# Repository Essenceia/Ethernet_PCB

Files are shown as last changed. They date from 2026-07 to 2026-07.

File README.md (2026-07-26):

# PCBs for Coffee-Shop project

## Biscotti 

x1 Ethernet Pmod for full-duplex 100BASE-TX over RMII using the LAN8720A chip. 

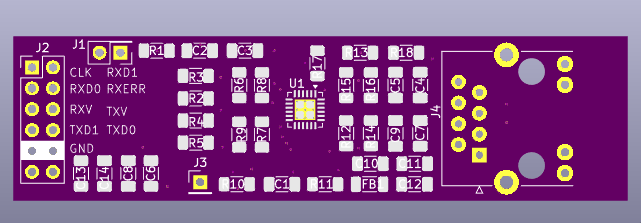
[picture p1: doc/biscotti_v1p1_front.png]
front

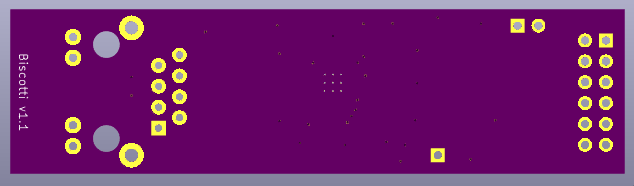
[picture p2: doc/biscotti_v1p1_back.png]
back


## AI Policy 

No AI was used by me in the development of this hardware. 

All code and design decisions are, and will remain, entirely human made. 

## License 

Copyright Julia Desmazes, 2026 

This hardware is distributed under the **strongly** reciprocal CERN Open Hardware Licence Version 2 unless
otherwise specified.

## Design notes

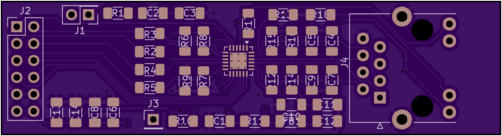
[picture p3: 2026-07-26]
doc/biscotti_v1_0_front.png

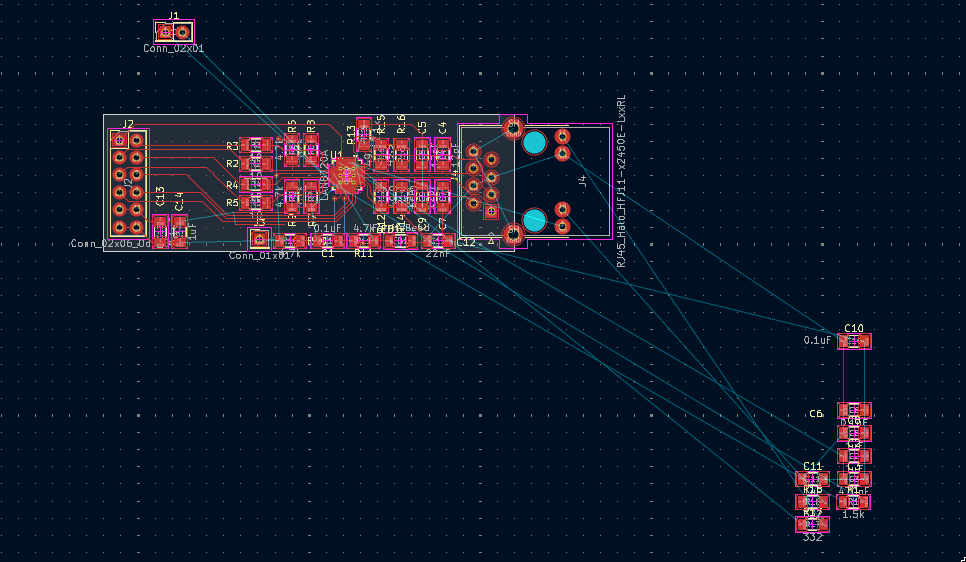
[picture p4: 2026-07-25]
doc/layout_biscotti_wip.png

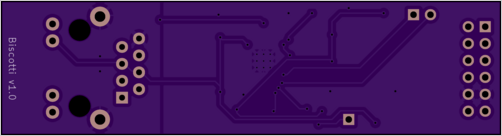
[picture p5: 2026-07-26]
doc/biscotti_v1_0_back.png

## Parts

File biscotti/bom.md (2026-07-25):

All right belong to Julia Desmazes, 2026.

This document is human made and authorization is explicitely 
not granted for this document to be used as part of any trainig 
or inference dataset. 

# LAN8720A 

PHY chip, 24-QFN

package: 24-QFN
 
part: LAN8720A-CP-TR
digikey part number: LAN8720A-CP-CT-ND

https://www.digikey.com/en/products/detail/microchip-technology/LAN8720A-CP-TR/3872109

# RJ45 Jack

ARJM11 Series of RJ45 Jacks, 100BASE-T, yellow-green leds

part: ARJM11D7-009-AB-EW2
digikey part number: 535-ARJM11D7-009-AB-EW2-ND

https://www.digikey.com/en/products/detail/abracon-llc/ARJM11D7-009-AB-EW2/7675229 

# 12pF Ceramic Capacitor

12pF ceramic capacitors for decoupling the data lines between the PHY chip and the RJ45 connector for EMI.
Targetting 1206 (i) flootprint (3216 m). 

package: 1206 

part: GMC31CG120J100NT
digikey part number: 4713-GMC31CG120J100NTCT-ND

https://www.digikey.com/en/products/detail/cal-chip-electronics-inc/GMC31CG120J100NT/25893198

# 49.9 ohm Resistor 

package: 1206 

part: RC1206FR-0749R9L
digikey part number: 311-49.9FRCT-ND

https://www.digikey.com/en/products/detail/yageo/RC1206FR-0749R9L/728942

# 332 ohm Resistor 

package: 1206 

part: RK73H2BTTD3320F
digikey part number: 2019-RK73H2BTTD3320FCT-ND

https://www.digikey.com/en/products/detail/koa-speer-electronics-inc/RK73H2BTTD3320F/10235876

# 22nF Ceramic Capacitor 

package: 1206

part: 1206B223K500CT
digikey part number: 1292-1609-1-ND

https://www.digikey.com/en/products/detail/walsin-technology-corporation/1206B223K500CT/9355106

# 12.1k ohm Resistor 

Used for RBIAS, need 12.1k 1% as per spec. 

package: 1206

part: RMCF1206FT12K1
digikey part number: RMCF1206FT12K1CT-ND

https://www.digikey.com/en/products/detail/stackpole-electronics-inc/RMCF1206FT12K1/1759578

# 1.5k ohm Resistor 

Used for pull-up of MDIO

package: 1206

part: RMCF1206JG1K50
digikey part number: RMCF1206JG1K50CT-ND

https://www.digikey.com/en/products/detail/stackpole-electronics-inc/RMCF1206JG1K50/1757378

# 4.7k ohm Resistor 

Used for pull-up of nRST, don't want to drive that from the logic. 

package: 1206 

part: RC1206FR-074K7L
digikey part number: 311-4.70KFRCT-ND

https://www.digikey.com/en/products/detail/yageo/RC1206FR-074K7L/728887

# 100nF (0.1uF) Ceramic capcitor

Pull nRST to GND during reset

package: 1206

part: C1206C104K5RACTU
digikey part number: 399-C1206C104K5RACTUCT-ND

https://www.digikey.com/en/products/detail/kemet/C1206C104K5RACTU/411248

# 1uF Cermaic capacitor

package: 1206

part: GMC31Y5V105Z50NT
digikey part number: 4713-GMC31Y5V105Z50NTCT-ND

https://www.digikey.com/en/products/detail/cal-chip-electronics-inc/GMC31Y5V105Z50NT/26225549

# 470pF Ceramic Capacitor 

package: 1206 

part: GMC31CG471J100NT
digikey part number: 4713-GMC31CG471J100NTCT-ND

https://www.digikey.com/en/products/detail/cal-chip-electronics-inc/GMC31CG471J100NT/25951946

# 10 ohm Resitor 

RX data lines

package: 1206

part: RMCF1206JT10R0
digikey part: RMCF1206JT10R0CT-ND

https://www.digikey.com/en/products/detail/stackpole-electronics-inc/RMCF1206JT10R0/1757340

# Power line Ferrit Bead

Seperate VDD and AVDD for noise, 390 Ohms @ 100MHz, 2A/50mOhm
package: 1206

part: MI1206L391R-10
digikey key: 240-2578-1-ND

https://www.digikey.com/en/products/detail/laird-signal-integrity-products/MI1206L391R-10/1287224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

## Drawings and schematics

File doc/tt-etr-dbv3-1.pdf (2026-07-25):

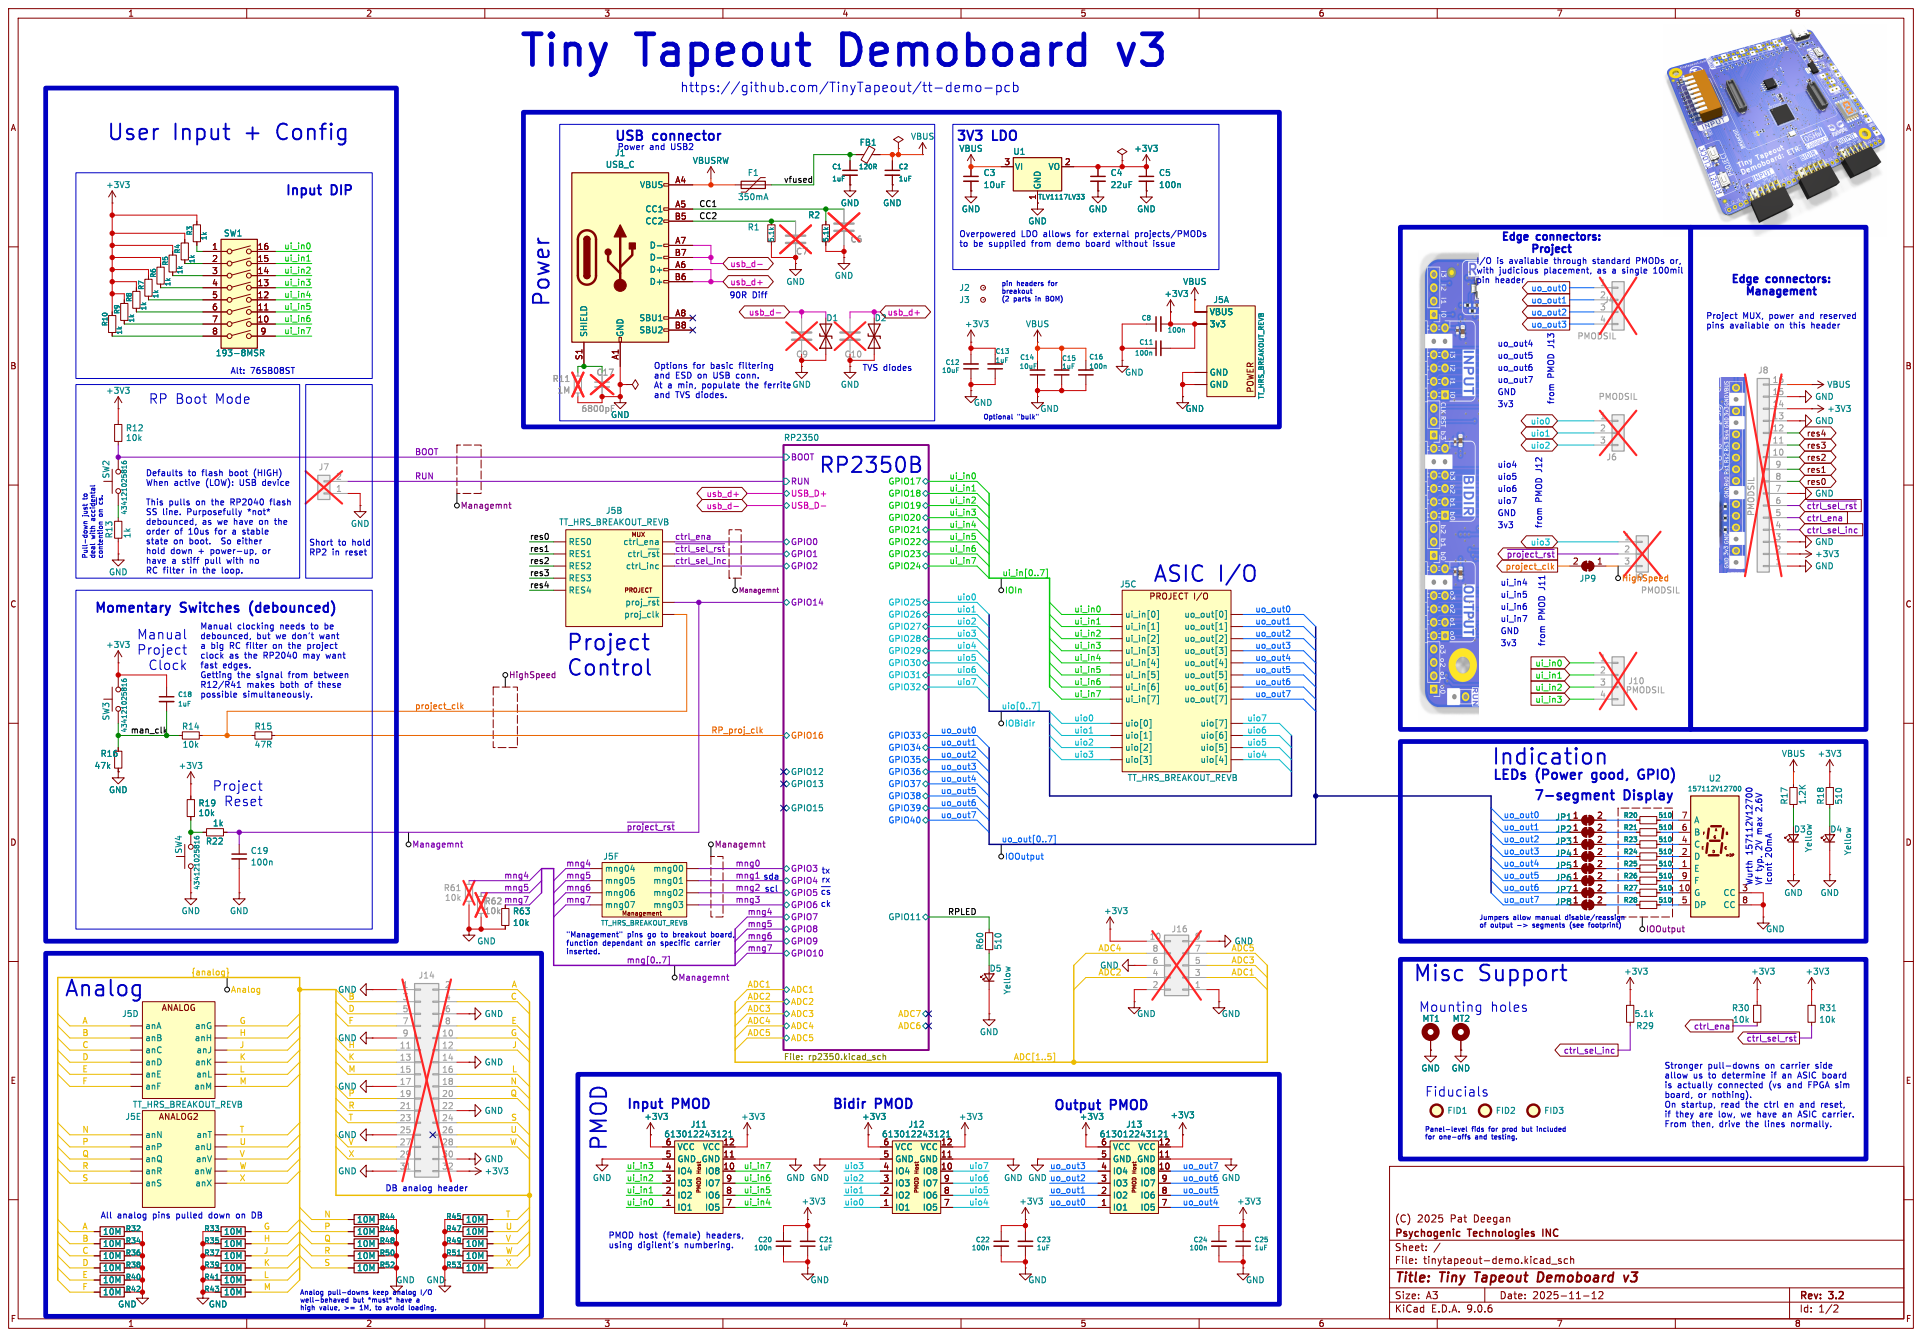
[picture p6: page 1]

Tiny Tapeout Demoboard v3 Pull-down just to deal with accidental contention on ~{cs}.

https://github.com/TinyTapeout/tt-demo-pcb
vfused

and TVS diodes. Input DIP

Edge connectors: Project from PMOD J12uio4
uo_out4

pin headers for breakout (2 parts in BOM)

Project MUX, power and reserved

Options for basic filtering

ck RP Boot Mode

order of 10us for a stable

Short to hold RP2 in reset

LEDs (Power good, GPIO)

Jumpers allow manual disable/reassign
Misc Support

if they are low, we have an ASIC carrier. From then, drive the lines normally.

Id: 1/2 Title: Tiny Tapeout Demoboard v3

high value, >= 1M, to avoid loading.

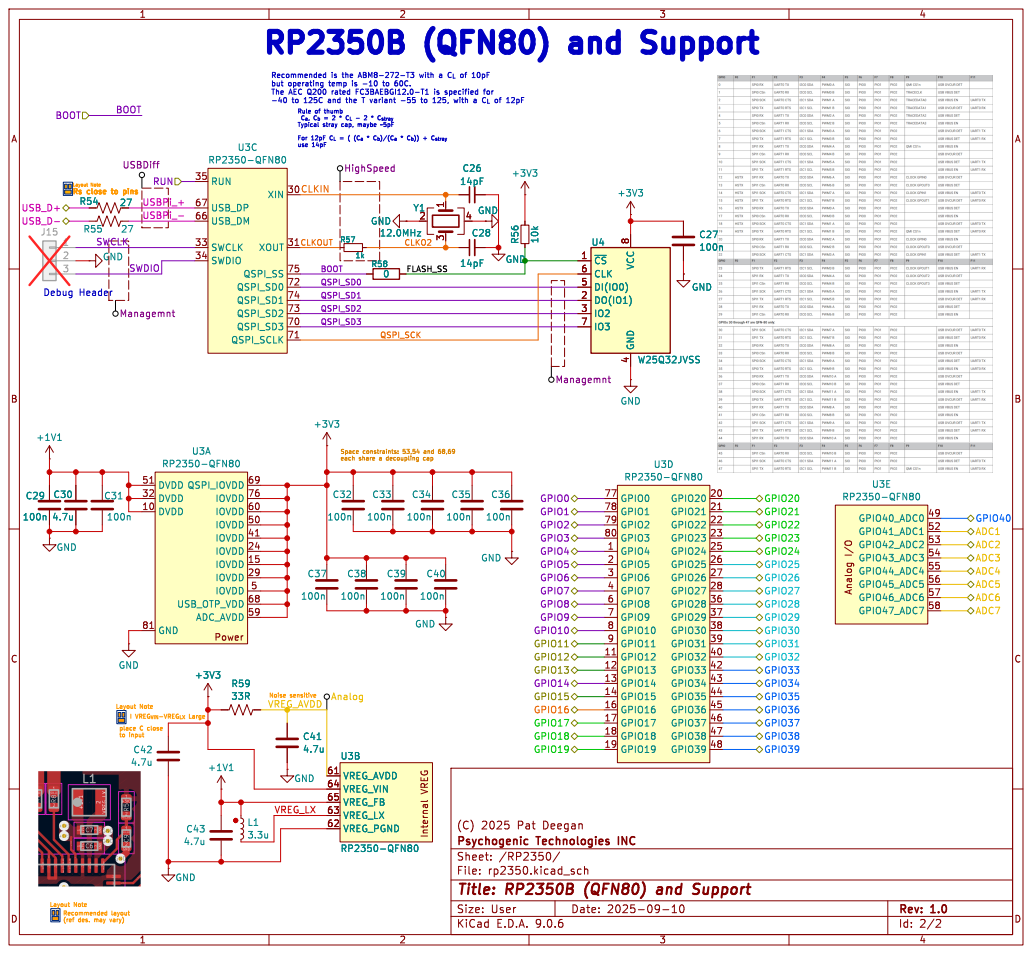
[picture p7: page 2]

Rule of thumb C_{a},C_{b}= 2 * C_{L}- 2 * C_{stray} Typical stray cap, maybe ~5pF

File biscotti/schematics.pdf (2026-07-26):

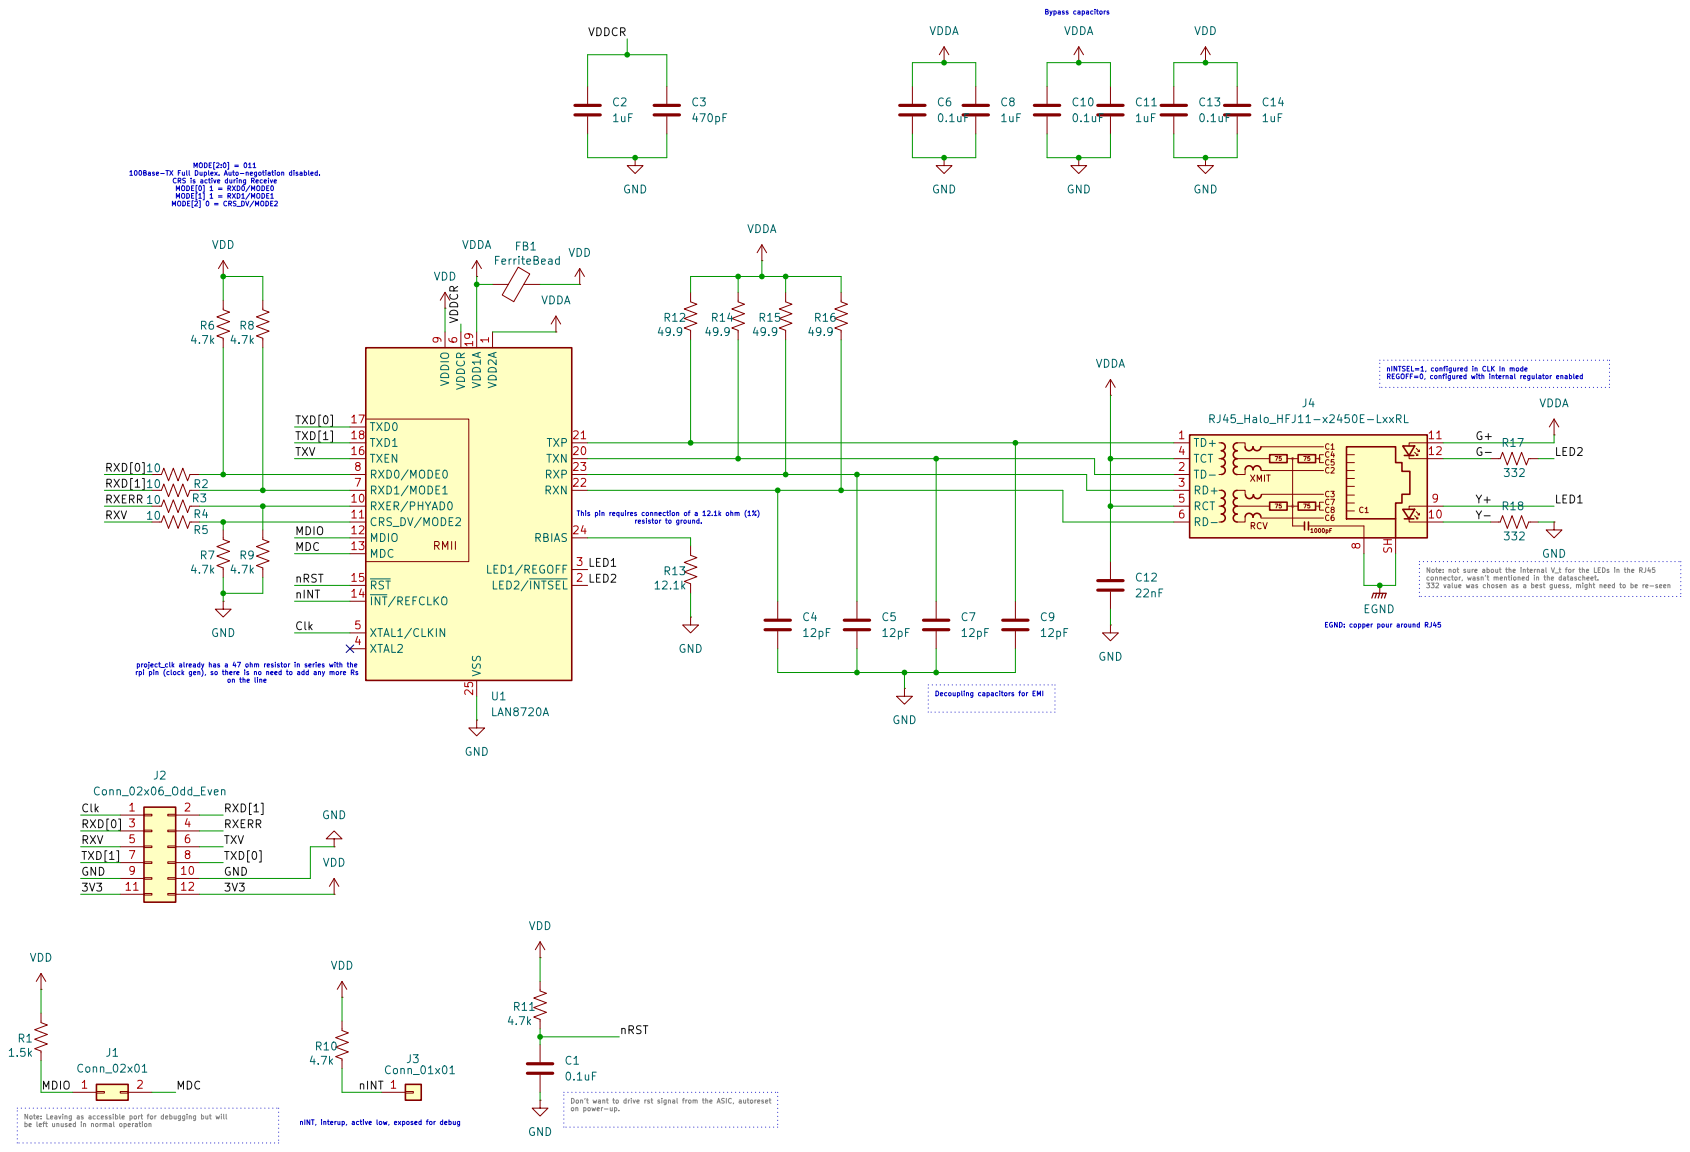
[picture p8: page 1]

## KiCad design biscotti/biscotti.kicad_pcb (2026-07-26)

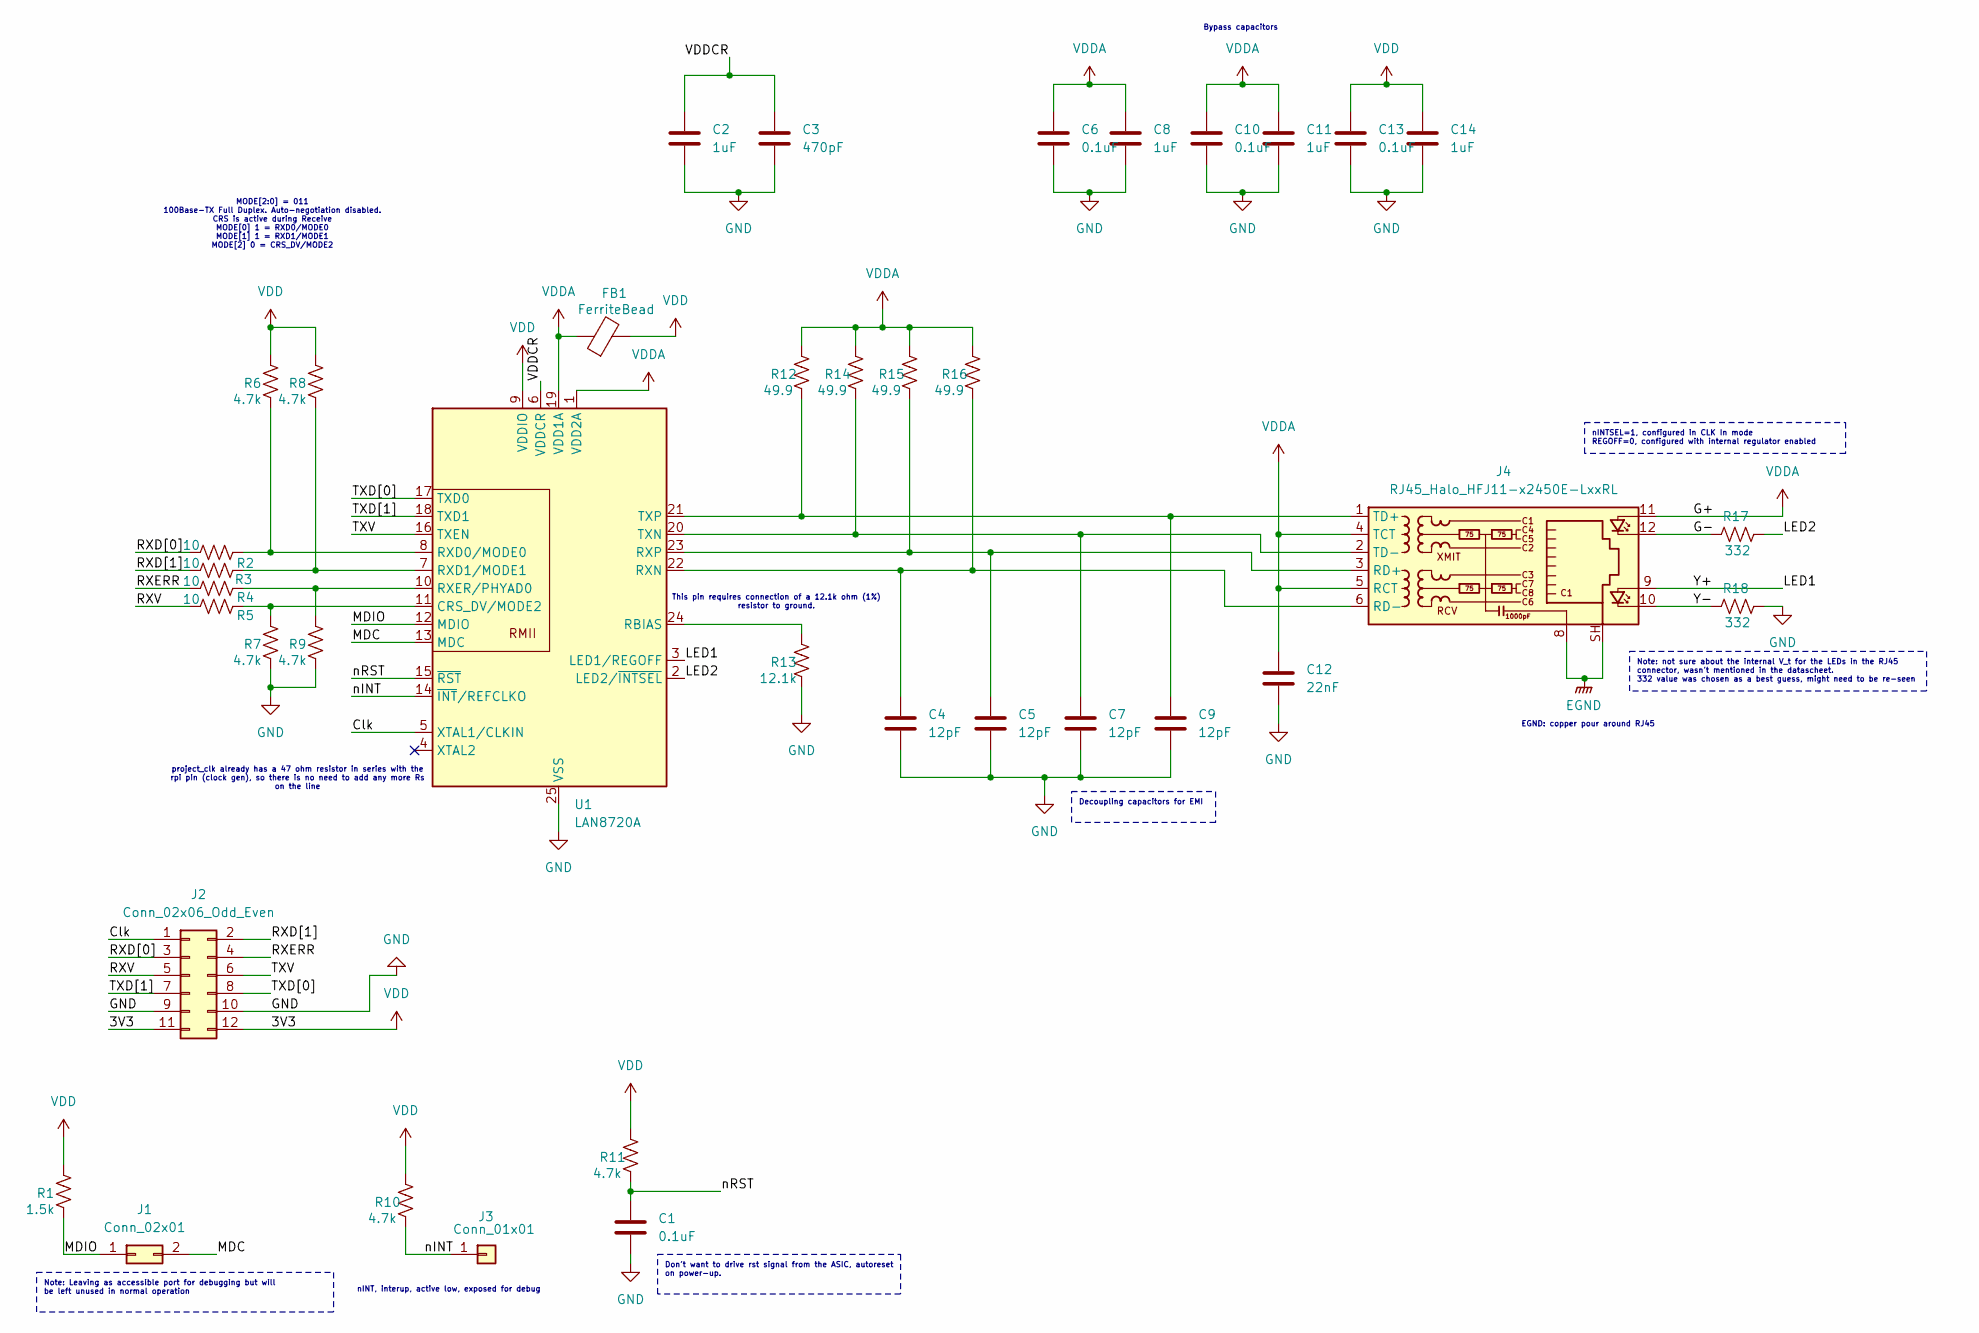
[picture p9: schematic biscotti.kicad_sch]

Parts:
C1, C6, C10, C13: 0.1uF; C_1206_3216Metric_Pad1.33x1.80mm_HandSolder
C2, C8, C11, C14: 1uF; C_1206_3216Metric_Pad1.33x1.80mm_HandSolder
C3: 470pF; C_1206_3216Metric_Pad1.33x1.80mm_HandSolder
C4, C5, C7, C9: 12pF; C_1206_3216Metric_Pad1.33x1.80mm_HandSolder
C12: 22nF; C_1206_3216Metric_Pad1.33x1.80mm_HandSolder
FB1: FerriteBead; L_1206_3216Metric_Pad1.22x1.90mm_HandSolder
J1: Conn_02x01; PinHeader_2x01_P2.54mm_Vertical
J2: Conn_02x06_Odd_Even; PinHeader_2x06_P2.54mm_Vertical
J3: Conn_01x01; PinHeader_1x01_P2.54mm_Vertical
J4: RJ45_Halo_HFJ11-x2450E-LxxRL; RJ45_HALO_HFJ11-x2450E-LxxRL_Horizontal
R1: 1.5k; R_1206_3216Metric_Pad1.30x1.75mm_HandSolder
R2, R3, R4, R5: 10; R_1206_3216Metric_Pad1.30x1.75mm_HandSolder
R6, R7, R8, R9, R10, R11: 4.7k; R_1206_3216Metric_Pad1.30x1.75mm_HandSolder
R12, R14, R15, R16: 49.9; R_1206_3216Metric_Pad1.30x1.75mm_HandSolder
R13: 12.1k; R_1206_3216Metric_Pad1.30x1.75mm_HandSolder
R17, R18: 332; R_1206_3216Metric_Pad1.30x1.75mm_HandSolder
U1: LAN8720A; VQFN-24-1EP_4x4mm_P0.5mm_EP2.5x2.5mm_ThermalVias

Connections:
/Clk: J2.1, U1.5 (XTAL1/CLKIN)
/G-: J4.12, R17.2
/LED1: J4.9, U1.3 (LED1/REGOFF)
/LED2: R17.1, U1.2 (LED2/~INTSEL)
/MDC: J1.2, U1.13 (MDC)
/MDIO: J1.1, R1.2, U1.12 (MDIO)
/RXD[0]: J2.3, R2.1
/RXD[1]: J2.2, R3.1
/RXERR: J2.4, R4.1
/RXV: J2.5, R5.1
/TXD[0]: J2.8, U1.17 (TXD0)
/TXD[1]: J2.7, U1.18 (TXD1)
/TXV: J2.6, U1.16 (TXEN)
/VDDCR: C2.1, C3.1, U1.6 (VDDCR)
/Y-: J4.10, R18.2
/nINT: J3.1 (Pin_1_1), R10.2, U1.14 (~INT/REFCLKO)
/nRST: C1.1, R11.2, U1.15 (~RST)
EGND: J4.8, J4.SH
GND: C1.2, C2.2, C3.2, C4.2, C5.2, C6.2, C7.2, C8.2, C9.2, C10.2, C11.2, C12.2, C13.2, C14.2, J2.9, J2.10, R7.2, R9.2, R13.2, R18.1, U1.25 (VSS)
unnamed: C5.1, J4.3 (RD+), R15.2, U1.23 (RXP)
unnamed: C4.1, J4.6 (RD-), R16.2, U1.22 (RXN)
unnamed: C9.1, J4.1 (TD+), R12.2, U1.21 (TXP)
unnamed: C7.1, J4.2 (TD-), R14.2, U1.20 (TXN)
unnamed: R5.2, R7.1, U1.11 (CRS_DV/MODE2)
unnamed: R13.1, U1.24 (RBIAS)
unnamed: R2.2, R6.2, U1.8 (RXD0/MODE0)
unnamed: R3.2, R8.2, U1.7 (RXD1/MODE1)
unnamed: R4.2, R9.1, U1.10 (RXER/PHYAD0)
VDD: C13.1, C14.1, FB1.2, J2.11, J2.12, R1.1, R6.1, R8.1, R10.1, R11.1, U1.9 (VDDIO)
VDDA: C6.1, C8.1, C10.1, C11.1, C12.1, FB1.1, J4.4 (TCT), J4.5 (RCT), J4.11, R12.1, R14.1, R15.1, R16.1, U1.1 (VDD2A), U1.19 (VDD1A)

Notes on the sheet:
This pin requires connection of a 12.1k ohm (1%) resistor to ground.
nINT, interup, active low, exposed for debug
MODE[2:0] = 011 100Base-TX Full Duplex. Auto-negotiation disabled. CRS is active during Receive MODE[0] 1 = RXD0/MODE0 MODE[1] 1 = RXD1/MODE1 MODE[2] 0 = CRS_DV/MODE2
project_clk already has a 47 ohm resistor in series with the rpi pin (clock gen), so there is no need to add any more Rs on the line
Bypass capacitors
EGND: copper pour around RJ45
Note: not sure about the internal V_t for the LEDs in the RJ45 connector, wasn't mentioned in the datascheet. 332 value was chosen as a best guess, might need to be re-seen
nINTSEL=1, configured in CLK In mode REGOFF=0, configured with internal regulator enabled
Decoupling capacitors for EMI
Don't want to drive rst signal from the ASIC, autoreset on power-up.
Note: Leaving as accessible port for debugging but will be left unused in normal operation

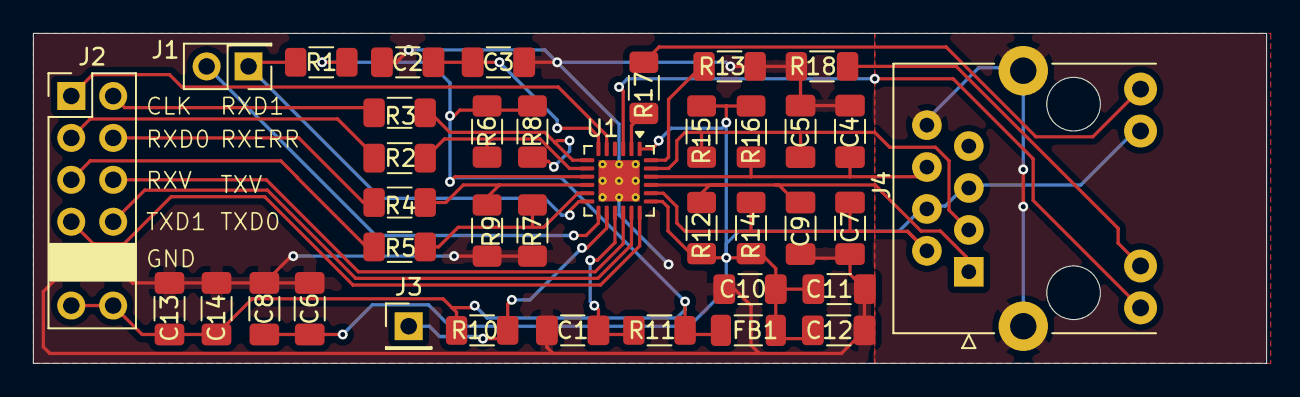
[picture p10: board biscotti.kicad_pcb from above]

Board: 2 copper layers, 74.8 x 20.0 mm, 38 parts (0 on the bottom side), 30 nets.

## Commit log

2026-07-22 looking for parts
    [biscotti.kicad_pcb, biscotti.kicad_sch]
2026-07-22 adding lan to bom
2026-07-22 add 49.9 ohm resistors
2026-07-23 wip, started connected configs for LED1/2
    [biscotti.kicad_sch]
2026-07-23 add pmod
    [biscotti.kicad_sch]
2026-07-24 config modes
    [biscotti.kicad_sch]
2026-07-25 finishing schematics and bom, next is routing
    [biscotti.kicad_sch]
2026-07-25 assign all footprints
    [biscotti.kicad_sch]
2026-07-25 placement in progress
    [biscotti.kicad_pcb, biscotti.kicad_sch]
2026-07-26 biscotti 1.0 and 1.1
    [biscotti-B_Cu.gbr, biscotti-B_Mask.gbr, biscotti-B_Paste.gbr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]
2026-07-26 add artifacts
    [biscotti.kicad_sch]
